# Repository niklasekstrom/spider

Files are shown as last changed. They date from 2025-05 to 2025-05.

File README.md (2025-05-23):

# SPIder

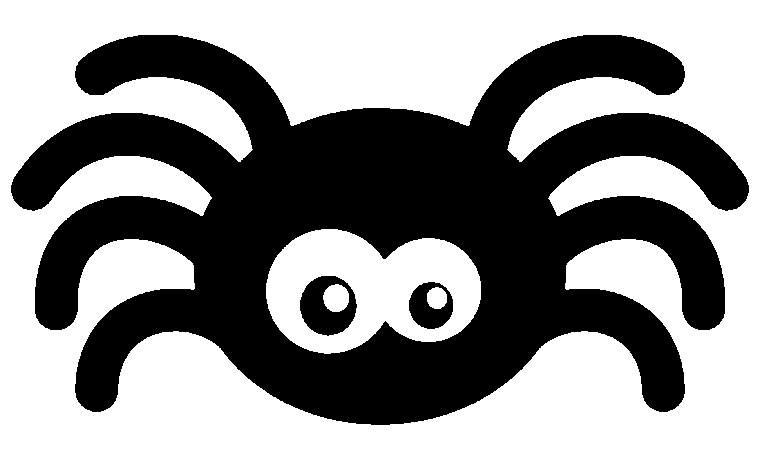
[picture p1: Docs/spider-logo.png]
SPIder logo


## Introduction

SPIder is an adapter that connects to the clockport on an Amiga, and provides
two SPI controllers and additional GPIO pins.

SPIder is built around the RP2040 microcontroller. GPIO pins 0..15 on the RP2040
are connected to the clockport, and pins 16..29 are available on a pin header.
GPIO pins 16..29 have multiple alternative functions. A table with the possible
functions for the GPIO pins are available in
[section 1.4.3](https://datasheets.raspberrypi.com/rp2040/rp2040-datasheet.pdf#page=13)
of the RP2040 datasheet.

## Architecture

This section contains a high level overview of the architecture of the firmware.
The RP2040 has two Cortex-M0+ ARM cores. One core is dedicated to responding to
clockport accesses (reads and writes). This has to be done in a time sensitive
manner as a clockport access lasts for less than a microsecond. The other core
communicates with the peripherals on the RP2040, such as the two SPI
controllers.

Architecture

## Bill of Materials (BOM)

| References | Value | Footprint | Quantity | JLCPCB |
|---|---|---|---|---|
| C5, C6, C7, C9, C11, C12, C13, C14, C15, C16, C18, C19, C20 | 100n | C_0402_1005Metric | 13 | [C1525](https://jlcpcb.com/partdetail/1877-CL05B104KO5NNNC/C1525) |
| C1, C4 | 10u | C_0805_2012Metric | 2 | [C15850](https://jlcpcb.com/partdetail/16532-CL21A106KAYNNNE/C15850) |
| C2, C3 | 15p | C_0402_1005Metric | 2 | [C1548](https://jlcpcb.com/partdetail/1900-0402CG150J500NT/C1548) |
| C8, C10 | 1u | C_0402_1005Metric | 2 | [C52923](https://jlcpcb.com/partdetail/53938-CL05A105KA5NQNC/C52923) |
| R2, R3 | 27 | R_0402_1005Metric | 2 | [C25105](https://jlcpcb.com/partdetail/25848-0402WGF330JTCE/C25105) |
| R1 | 10k | R_0402_1005Metric | 1 | [C25744](https://jlcpcb.com/partdetail/26487-0402WGF1002TCE/C25744) |
| R5 | 1k | R_0402_1005Metric | 1 | [C11702](https://jlcpcb.com/partdetail/12256-0402WGF1001TCE/C11702) |
| U1 | RP2040 | QFN-56-1EP_7x7mm_P0.4mm_EP3.2x3.2mm | 1 | [C2040](https://jlcpcb.com/partdetail/RaspberryPi-RP2040/C2040) |
| Y1 | ABM8-272-T3 | Crystal_SMD_3225-4Pin_3.2x2.5mm | 1 | [C20625731](https://jlcpcb.com/partdetail/AbraconLlc-ABM8_272T3/C20625731) |
| IC1 | SN74CBTD3384CPWR | TSSOP-24_4.4x7.8mm_P0.65mm | 1 | [C484747](https://jlcpcb.com/partdetail/TexasInstruments-SN74CBTD3384CPWR/C484747) |
| IC2 | SN74LVC125AIPWREP | TSSOP-14_4.4x5mm_P0.65mm | 1 | [C7813](https://jlcpcb.com/partdetail/TexasInstruments-SN74LVC125APWR/C7813) |
| IC3 | SN74LVC2G32DCUR | VSSOP-8_2.3x2mm_P0.5mm | 1 | [C91874](https://jlcpcb.com/partdetail/TexasInstruments-SN74LVC2G32DCUR/C91874) |
| IC4 | W25Q32RVXHJQ_TR | Winbond_USON-8-1EP_3x2mm_P0.5mm_EP0.2x1.6mm | 1 | [C5258281](https://jlcpcb.com/partdetail/Zetta-ZD25WQ32CEIGR/C5258281) |
| IC5 | TLV1117LV33DCYR | SOT-223 | 1 | [C15578](https://jlcpcb.com/partdetail/TexasInstruments-TLV1117LV33DCYR/C15578) |
| J1 | Conn_02x11_Odd_Even | PinSocket_2x11_P2.00mm_Vertical | 1 | |
| J2 | Conn_02x10_Odd_Even | PinHeader_2x10_P2.54mm_Horizontal | 1 | |
| J3 | Conn_01x03 | PinHeader_1x03_P2.54mm_Vertical | 1 | |
| J4 | Conn_01x05 | PinHeader_1x05_P2.54mm_Vertical | 1 | |

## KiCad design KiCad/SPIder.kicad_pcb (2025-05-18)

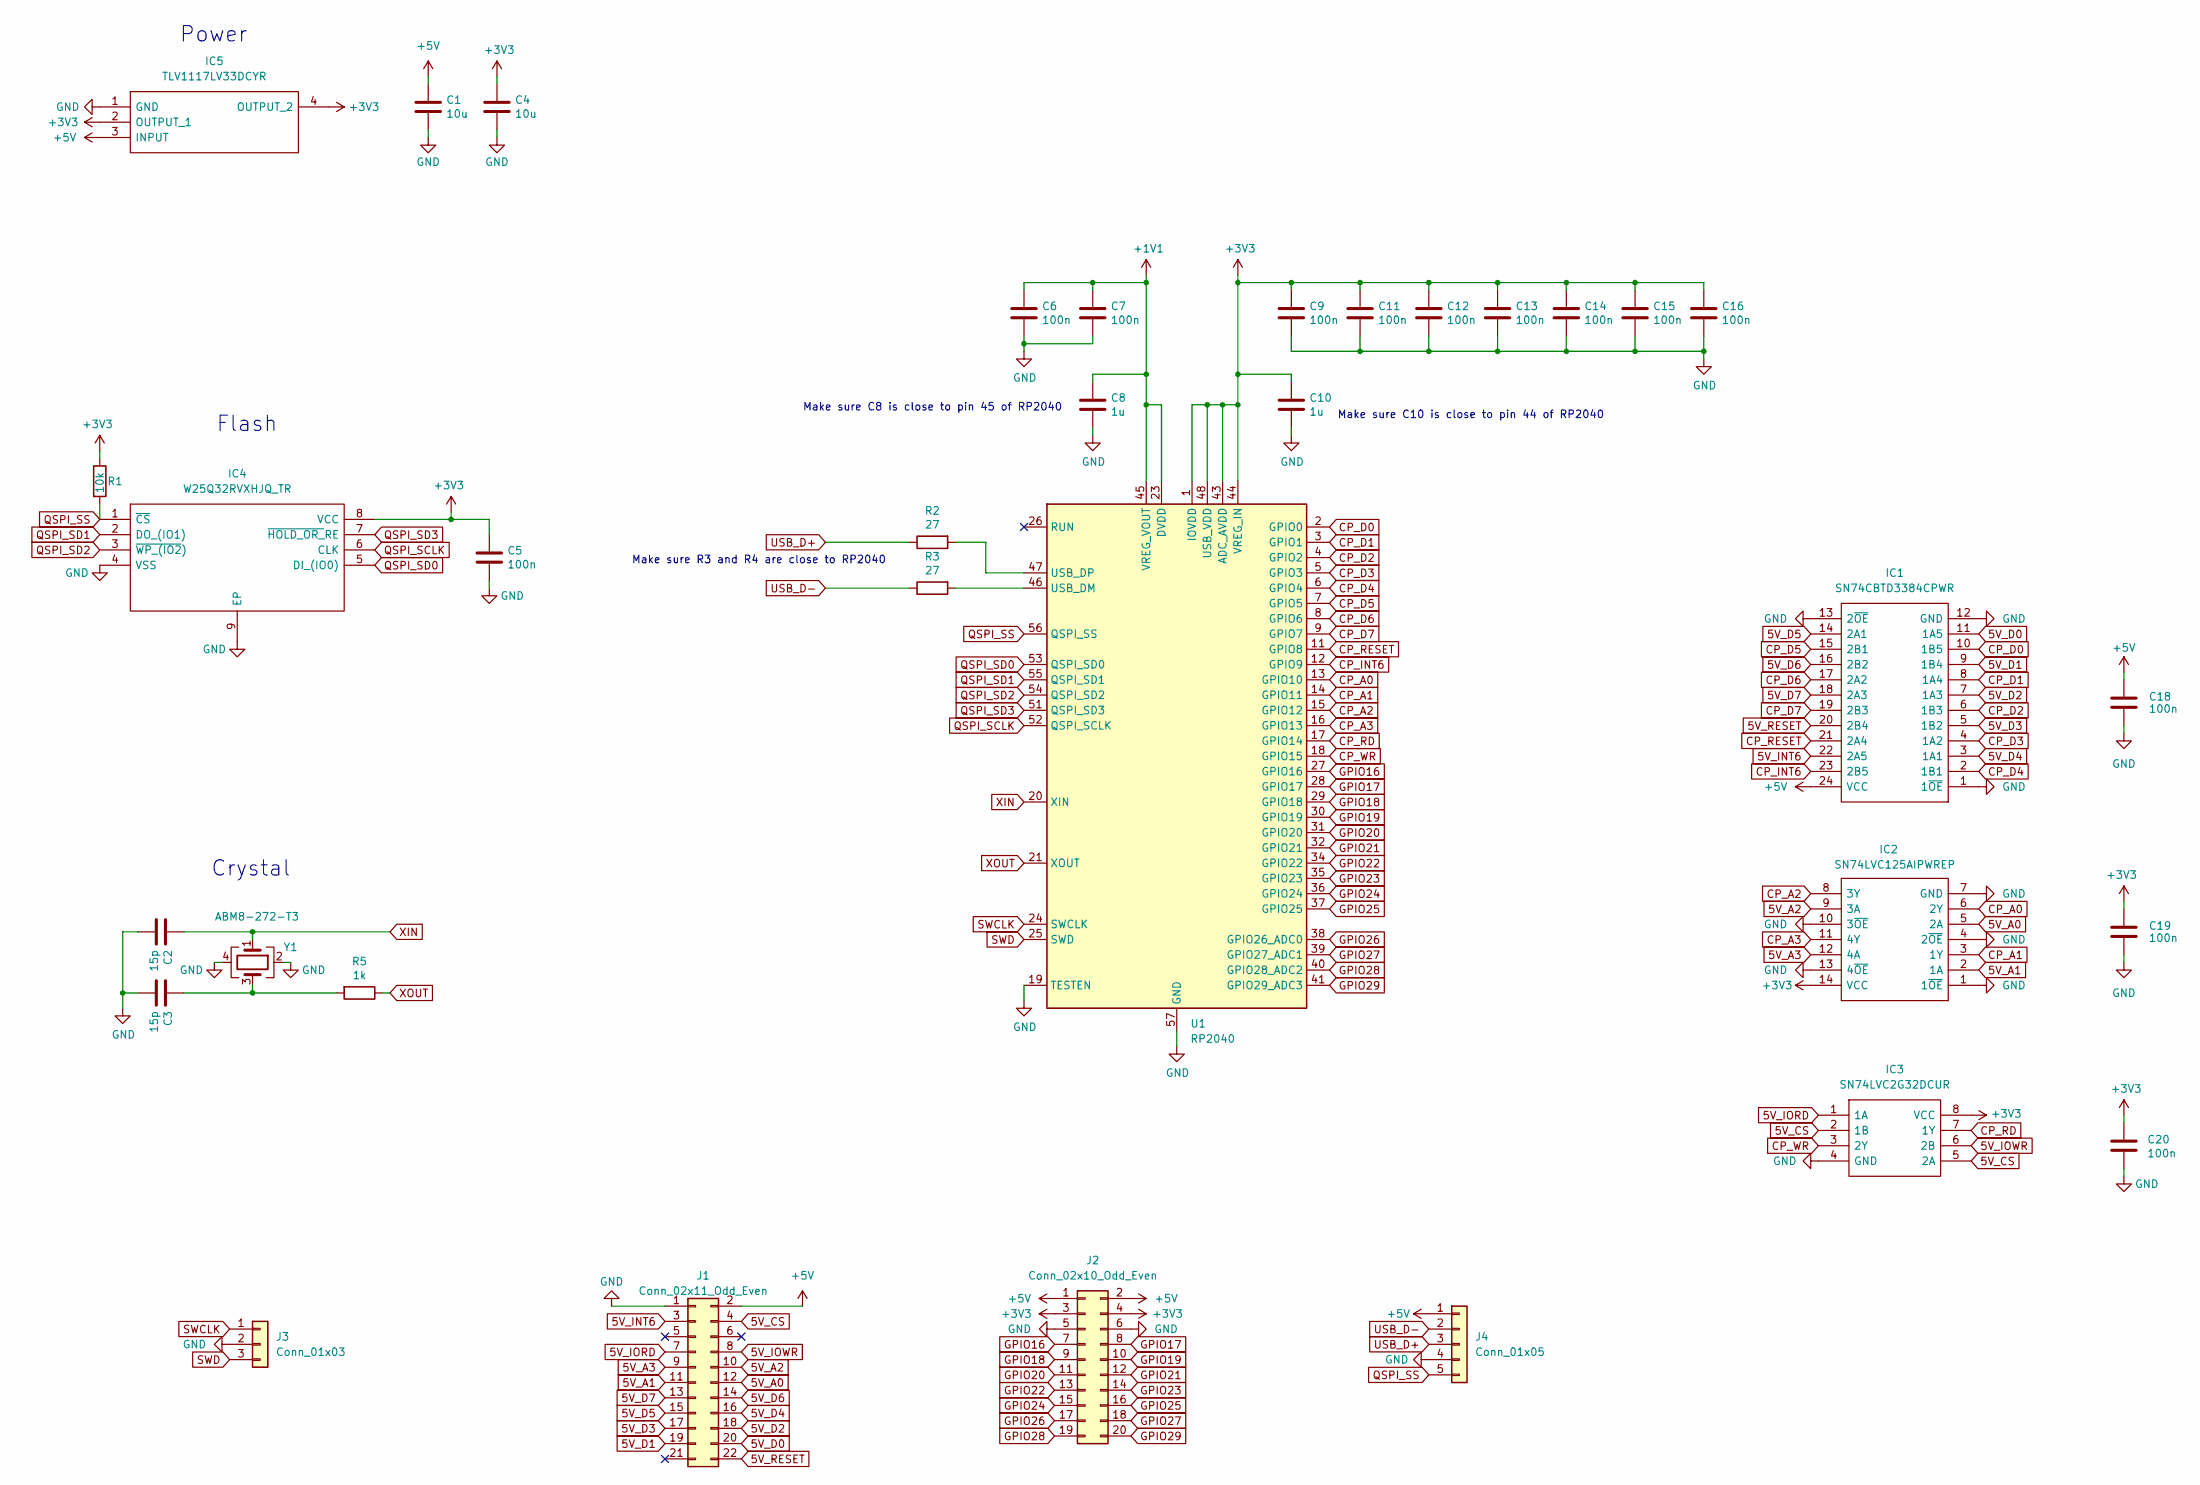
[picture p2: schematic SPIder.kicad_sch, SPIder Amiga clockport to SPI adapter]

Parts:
C1, C4: 10u; C_0805_2012Metric
C2, C3: 15p; C_0402_1005Metric
C5, C6, C7, C9, C11, C12, C13, C14, C15, C16, C18, C19, C20: 100n; C_0402_1005Metric
C8, C10: 1u; C_0402_1005Metric
IC1: SN74CBTD3384CPWR; TSSOP-24_4.4x7.8mm_P0.65mm; Mouser Part Number 595-SN74CBTD3384CPWR
IC2: SN74LVC125AIPWREP; TSSOP-14_4.4x5mm_P0.65mm; Mouser Part Number 595-N74LVC125AIPWREP
IC3: SN74LVC2G32DCUR; VSSOP-8_2.3x2mm_P0.5mm; Mouser Part Number 595-SN74LVC2G32DCUR
IC4: W25Q32RVXHJQ_TR; Winbond_USON-8-1EP_3x2mm_P0.5mm_EP0.2x1.6mm; Mouser Part Number 454-W25Q32RVXHJQTR
IC5: TLV1117LV33DCYR; SOT-223; Mouser Part Number 595-TLV1117LV33DCYR
J1: Conn_02x11_Odd_Even; PinSocket_2x11_P2.00mm_Vertical
J2: Conn_02x10_Odd_Even; PinHeader_2x10_P2.54mm_Horizontal
J3: Conn_01x03; PinHeader_1x03_P2.54mm_Vertical
J4: Conn_01x05; PinHeader_1x05_P2.54mm_Vertical
R1: 10k; R_0402_1005Metric
R2, R3: 27; R_0402_1005Metric
R5: 1k; R_0402_1005Metric
U1: RP2040; QFN-56-1EP_7x7mm_P0.4mm_EP3.2x3.2mm
Y1: ABM8-272-T3; Crystal_SMD_3225-4Pin_3.2x2.5mm

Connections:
5V_A0: IC2.5 (2A), J1.12
5V_A1: IC2.2 (1A), J1.11
5V_A2: IC2.9 (3A), J1.10
5V_A3: IC2.12 (4A), J1.9
5V_CS: IC3.2 (1B), IC3.5 (2A), J1.4
5V_D0: IC1.11 (1A5), J1.20
5V_D1: IC1.9 (1B4), J1.19
5V_D2: IC1.7 (1A3), J1.18
5V_D3: IC1.5 (1B2), J1.17
5V_D4: IC1.3 (1A1), J1.16
5V_D5: IC1.14 (2A1), J1.15
5V_D6: IC1.16 (2B2), J1.14
5V_D7: IC1.18 (2A3), J1.13
5V_INT6: IC1.22 (2A5), J1.3
5V_IORD: IC3.1 (1A), J1.7
5V_IOWR: IC3.6 (2B), J1.8
5V_RESET: IC1.20 (2B4), J1.22
+1V1: C6.1, C7.1, C8.1, U1.23 (DVDD), U1.45 (VREG_VOUT), U1.50 (DVDD)
+3V3: C4.1, C5.1, C9.1, C10.1, C11.1, C12.1, C13.1, C14.1, C15.1, C16.1, C19.1, C20.1, IC2.14 (VCC), IC3.8 (VCC), IC4.8 (VCC), IC5.2 (OUTPUT_1), IC5.4 (OUTPUT_2), J2.3, J2.4, R1.1, U1.1 (IOVDD), U1.10 (IOVDD), U1.22 (IOVDD), U1.33 (IOVDD), U1.42 (IOVDD), U1.43 (ADC_AVDD), U1.44 (VREG_IN), U1.48 (USB_VDD), U1.49 (IOVDD)
+5V: C1.1, C18.1, IC1.24 (VCC), IC5.3 (INPUT), J1.2, J2.1, J2.2, J4.1
CP_A0: IC2.6 (2Y), U1.13 (GPIO10)
CP_A1: IC2.3 (1Y), U1.14 (GPIO11)
CP_A2: IC2.8 (3Y), U1.15 (GPIO12)
CP_A3: IC2.11 (4Y), U1.16 (GPIO13)
CP_D0: IC1.10 (1B5), U1.2 (GPIO0)
CP_D1: IC1.8 (1A4), U1.3 (GPIO1)
CP_D2: IC1.6 (1B3), U1.4 (GPIO2)
CP_D3: IC1.4 (1A2), U1.5 (GPIO3)
CP_D4: IC1.2 (1B1), U1.6 (GPIO4)
CP_D5: IC1.15 (2B1), U1.7 (GPIO5)
CP_D6: IC1.17 (2A2), U1.8 (GPIO6)
CP_D7: IC1.19 (2B3), U1.9 (GPIO7)
CP_INT6: IC1.23 (2B5), U1.12 (GPIO9)
CP_RD: IC3.7 (1Y), U1.17 (GPIO14)
CP_RESET: IC1.21 (2A4), U1.11 (GPIO8)
CP_WR: IC3.3 (2Y), U1.18 (GPIO15)
GND: C1.2, C2.2, C3.2, C4.2, C5.2, C6.2, C7.2, C8.2, C9.2, C10.2, C11.2, C12.2, C13.2, C14.2, C15.2, C16.2, C18.2, C19.2, C20.2, IC1.1 (1~OE), IC1.12 (GND), IC1.13 (2~OE), IC2.1 (1~OE), IC2.4 (2~OE), IC2.7 (GND), IC2.10 (3~OE), IC2.13 (4~OE), IC3.4 (GND), IC4.4 (VSS), IC4.9 (EP), IC5.1 (GND), J1.1, J2.5, J2.6, J3.2, J4.4, U1.19 (TESTEN), U1.57 (GND), Y1.2, Y1.4
GPIO16: J2.7, U1.27 (GPIO16)
GPIO17: J2.8, U1.28 (GPIO17)
GPIO18: J2.9, U1.29 (GPIO18)
GPIO19: J2.10, U1.30 (GPIO19)
GPIO20: J2.11, U1.31 (GPIO20)
GPIO21: J2.12, U1.32 (GPIO21)
GPIO22: J2.13, U1.34 (GPIO22)
GPIO23: J2.14, U1.35 (GPIO23)
GPIO24: J2.15, U1.36 (GPIO24)
GPIO25: J2.16, U1.37 (GPIO25)
GPIO26: J2.17, U1.38 (GPIO26_ADC0)
GPIO27: J2.18, U1.39 (GPIO27_ADC1)
GPIO28: J2.19, U1.40 (GPIO28_ADC2)
GPIO29: J2.20, U1.41 (GPIO29_ADC3)
unnamed: C3.1, R5.2, Y1.3
unnamed: R3.2, U1.46 (USB_DM)
unnamed: R2.2, U1.47 (USB_DP)
QSPI_SCLK: IC4.6 (CLK), U1.52 (QSPI_SCLK)
QSPI_SD0: IC4.5 (DI_(IO0)), U1.53 (QSPI_SD0)
QSPI_SD1: IC4.2 (DO_(IO1)), U1.55 (QSPI_SD1)
QSPI_SD2: IC4.3 (~WP_(IO2)), U1.54 (QSPI_SD2)
QSPI_SD3: IC4.7 (~HOLD_OR_RE), U1.51 (QSPI_SD3)
QSPI_SS: IC4.1 (~CS), J4.5, R1.2, U1.56 (QSPI_SS)
SWCLK: J3.1, U1.24 (SWCLK)
SWD: J3.3, U1.25 (SWD)
USB_D+: J4.3, R2.1
USB_D-: J4.2, R3.1
XIN: C2.1, U1.20 (XIN), Y1.1
XOUT: R5.1, U1.21 (XOUT)

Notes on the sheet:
Power
Crystal
Make sure C8 is close to pin 45 of RP2040
Make sure R3 and R4 are close to RP2040
Make sure C10 is close to pin 44 of RP2040
Flash

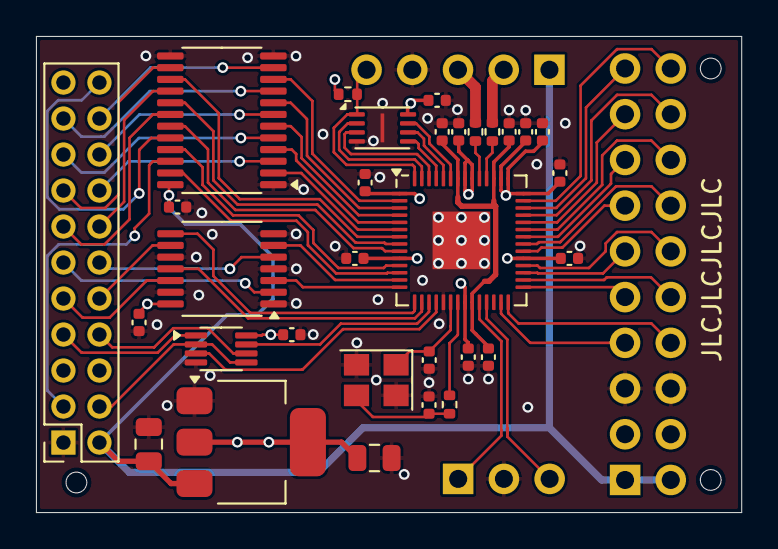
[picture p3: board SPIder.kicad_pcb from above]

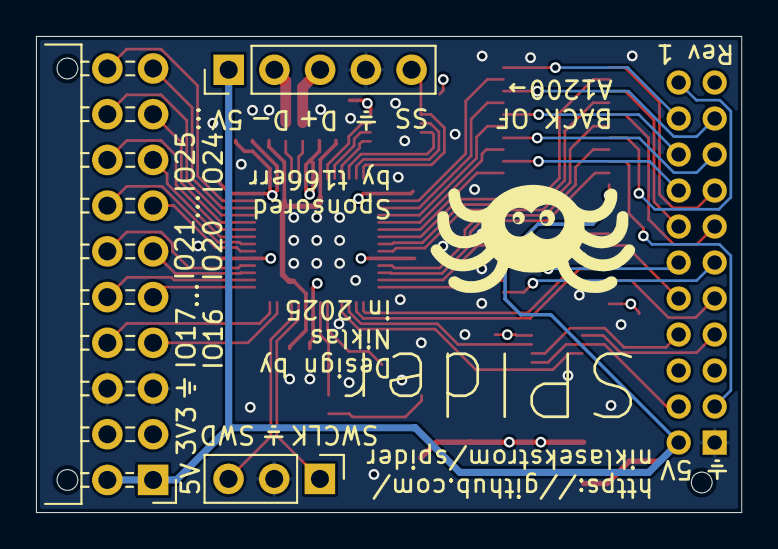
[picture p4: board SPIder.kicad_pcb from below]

Board: 4 copper layers, 39.2 x 26.5 mm, 34 parts (3 on the bottom side), 66 nets.

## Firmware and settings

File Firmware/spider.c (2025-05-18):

/*
 * Written in April 2025 by Niklas Ekström.
 *
 * SPIder exposes two SPI interfaces to the Amiga through the clockport.
 */
#include "hardware/gpio.h"
#include "hardware/spi.h"

#include "pico/critical_section.h"
#include "pico/multicore.h"
#include "pico/stdlib.h"

#include <stdio.h>

#include "protocol.h"

// SemVer: Major.Minor.Patch.
#define FIRMWARE_MAJOR_VERSION  1
#define FIRMWARE_MINOR_VERSION  0
#define FIRMWARE_PATCH_VERSION  0

// Identification.
#define IDENT_SIZE              8
#define IDENT_BYTES             {0xff, 's', 'p', 'd', 'r', FIRMWARE_MAJOR_VERSION, FIRMWARE_MINOR_VERSION, FIRMWARE_PATCH_VERSION}

#define DEBOUNCE_DOUBLE_READ    1
#define DEBOUNCE_DELAY_AFTER    1

// On the RP2040, setting both pulls enables a "bus keep" function,
// i.e. a weak pull to whatever is current high/low state of GPIO.
#define CTRL_PULL_UP            true
#define CTRL_PULL_DOWN          true

#define TEN_KHZ                 10000
#define ONE_MHZ                 1000000

#define SYS_CLOCK_KHZ           200000

#define SPI_RESET_FREQUENCY     (400*1000)

//      Pin name    GPIO    Direction   Comment     Description
#define PIN_D(x)    (0+x)   // In/out
#define PIN_RESET   8       // Input    Active low
#define PIN_INT6    9       // Output   Open collector
#define PIN_A(x)    (10+x)  // Input
#define PIN_RD      14      // Input    Active low
#define PIN_WR      15      // Input    Active low
#define PIN_MISO    16      // Input    Pull-up
#define PIN_SS      17      // Output   Active low
#define PIN_SCK     18      // Output
#define PIN_MOSI    19      // Output
#define PIN_CDET    20      // Input    Pull-up     Card Detect

// Application core commands.
#define APC_NOP                 0
#define APC_RESET               1
#define APC_UPPER_BYTE          2
#define APC_RX_DISCARD          3
#define APC_TX_FEED             4
#define APC_SPI_FREQ            5
#define APC_SLAVE_SELECT        6

static uint8_t ident_data[IDENT_SIZE] = IDENT_BYTES;
static uint8_t ident_index;

static volatile uint8_t registers[16];

static uint8_t rx_fifo[256];
static uint8_t tx_fifo[256];

static bool running;
static uint8_t in_flight;
static uint8_t upper_byte;

static uint32_t rx_discard_bytes_left;
static uint32_t tx_feed_bytes_left;

// #############################################################################
// ##### Logger macros
// #############################################################################

#define LOGGER_TRACE 0
#define logger_trace(...) do { if (LOGGER_TRACE) printf(__VA_ARGS__); } while (0)

#define LOGGER_DEBUG 0
#define logger_debug(...) do { if (LOGGER_DEBUG) printf(__VA_ARGS__); } while (0)

#define LOGGER_INFO 1
#define logger_info(...) do { if (LOGGER_INFO) printf(__VA_ARGS__); } while (0)

#define LOGGER_WARNING 1
#define logger_warning(...) do { if (LOGGER_WARNING) printf(__VA_ARGS__); } while (0)

#define LOGGER_ERROR 1
#define logger_error(...) do { if (LOGGER_ERROR) printf(__VA_ARGS__); } while (0)

// #############################################################################
// ##### These functions execute on the app core
// #############################################################################

static inline void set_int_fired(uint8_t data)
{
    if (registers[REG_INT_FIRED])
        return;

    if ((registers[REG_INT_ARMED] & data) == 0)
        return;

    gpio_set_dir_out_masked(1 << PIN_INT6);
    registers[REG_INT_FIRED] = 1;
}

static void handle_reset()
{
    logger_info("RESET\n");

    registers[REG_INT_ARMED] = 0;
    registers[REG_INT_FIRED] = 0;
    gpio_set_dir_in_masked(1 << PIN_INT6);

    running = false;
    in_flight = 0;
    upper_byte = 0;

    rx_discard_bytes_left = 0;
    tx_feed_bytes_left = 0;

    registers[REG_RX_HEAD] = 0;
    registers[REG_RX_TAIL] = 0;
    registers[REG_TX_HEAD] = 0;
    registers[REG_TX_TAIL] = 0;

    spi_set_baudrate(spi0, SPI_RESET_FREQUENCY);
}

static void handle_spi_freq(uint32_t data)
{
    uint32_t freq = data < 128 ? (data * TEN_KHZ) : ((data - 128) * ONE_MHZ);

    logger_info("SPI_FREQ, freq=%d\n", freq);

    spi_set_baudrate(spi0, freq);
}

static void handle_slave_select(uint32_t data)
{
    gpio_put(PIN_SS, data == 1 ? 0 : 1);
}

static void handle_upper_byte(uint32_t data)
{
    upper_byte = (uint8_t)data;
}

static void handle_rx_discard(uint32_t data)
{
    uint32_t increment = (upper_byte << 8) | (data & 0xff);
    rx_discard_bytes_left += increment;
    upper_byte = 0;
}

static void handle_tx_feed(uint32_t data)
{
    uint32_t increment = (upper_byte << 8) | (data & 0xff);
    tx_feed_bytes_left += increment;
    upper_byte = 0;
}

static void handle_apc_cmd()
{
    if (multicore_fifo_rvalid())
    {
        uint32_t value = sio_hw->fifo_rd;
        uint32_t cmd = value & 0xff;
        uint32_t data = value >> 8;

        switch (cmd)
        {
            case APC_RESET: handle_reset(); break;
            case APC_UPPER_BYTE: handle_upper_byte(data); break;
            case APC_RX_DISCARD: handle_rx_discard(data); break;
            case APC_TX_FEED: handle_tx_feed(data); break;
            case APC_SPI_FREQ: handle_spi_freq(data); break;
            case APC_SLAVE_SELECT: handle_slave_select(data); break;
            default: break;
        }

        running = cmd != APC_RESET;
    }
}

static void handle_gpio_interrupts()
{
    uint8_t card_detect = (gpio_get_all() & (1 << PIN_CDET)) == 0 ? 1 : 0;

    if (card_detect != registers[REG_CARD_DETECT])
    {
        registers[REG_CARD_DETECT] = card_detect;
        set_int_fired(IRQ_CD_CHANGED);
    }
}

static void handle_fifo_data()
{
    uint8_t rx_fifo_tail = registers[REG_RX_TAIL];

    // Read as many bytes as possible from SPI-RX.
    while (spi_is_readable(spi0))
    {
        if (rx_discard_bytes_left)
        {
            (void) spi_get_hw(spi0)->dr;
            rx_discard_bytes_left--;
        }
        else
        {
            uint8_t next_rx_fifo_tail = rx_fifo_tail + 1;
            if (next_rx_fifo_tail == registers[REG_RX_HEAD])
                break; // No space in RX-FIFO.

            rx_fifo[rx_fifo_tail] = (uint8_t) spi_get_hw(spi0)->dr;

            rx_fifo_tail = next_rx_fifo_tail;
            registers[REG_RX_TAIL] = next_rx_fifo_tail;
        }

        in_flight--;
    }

    uint8_t tx_fifo_head = registers[REG_TX_HEAD];

    // Write as many bytes as possible to SPI-TX.
    while (in_flight != 8 && spi_is_writable(spi0))
    {
        if (tx_fifo_head != registers[REG_TX_TAIL])
        {
            spi_get_hw(spi0)->dr = (uint32_t) tx_fifo[tx_fifo_head];

            tx_fifo_head++;
            registers[REG_TX_HEAD] = tx_fifo_head;
        }
        else if (tx_feed_bytes_left)
        {
            spi_get_hw(spi0)->dr = (uint32_t) 0xff;

            tx_feed_bytes_left--;
        }
        else
            break; // No bytes to write.

        in_flight++;
    }
}
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

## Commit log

2025-05-18 Initial commit, revision 1
    [SPIder.kicad_pcb, SPIder.kicad_sch]
2025-05-23 Update README with more text and BOM
